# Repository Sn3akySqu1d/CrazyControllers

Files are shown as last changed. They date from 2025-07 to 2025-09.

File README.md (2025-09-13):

# Crazy Controllers

# *Configurable machine learning computer interface glove and joystick*

ARE YOU FINDING GAMES TO HARD?  
DO YOU STRUGGLE WITH ALL THOSE EXTRA KEYS?  
DO YOU WANT TO FEEL SPIRITUALLY CONNECTED TO YOUR SCREEN?  

Well do we have the device for you with crazy controllers.

Crazy controllers presents two unique ways of controlling the game.

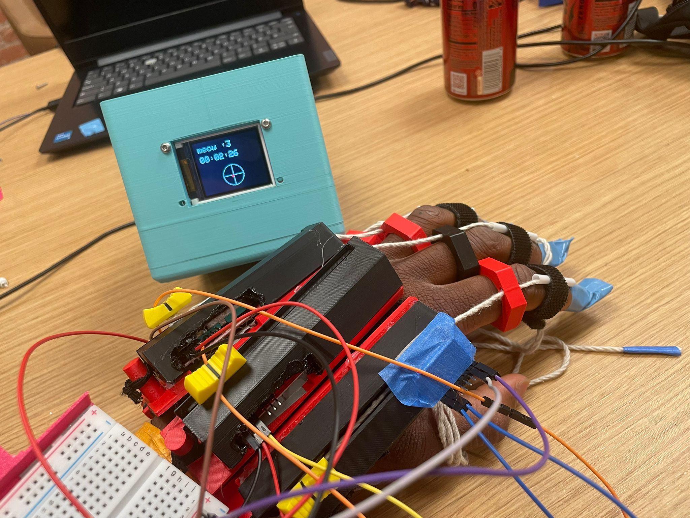
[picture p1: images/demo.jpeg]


## THE GLOVE.

Inspired by the Nintendo Power Glove we created a gauntlet that is able to recognise different gestures based on the position of your hand using an artificial neural network. Allowing you to control your computer and games in fun, unique ways.



We used potentiometer analog sliders and an IMU to read the current state of the hand position, the IMU providing the detail on the orientation of the hand using its accelerometer and using the analogue sliders connected to strings in antagonistic pairs to find out the extension of each finger. These sensor values are then sent along the serial monitor and parsed by a python script running on the computer which uses them to predict the current gesture based on a large csv file contianing sensor values and their corresponding gestures.

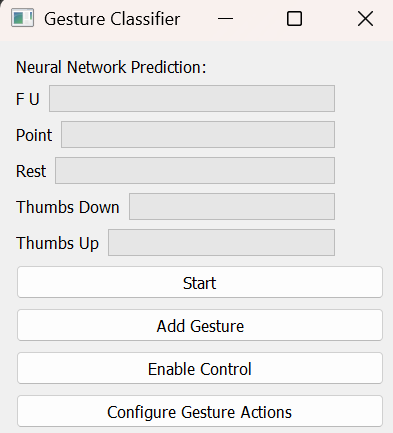
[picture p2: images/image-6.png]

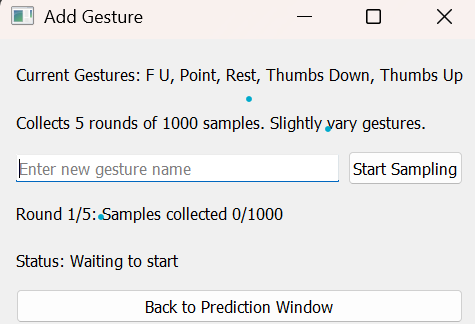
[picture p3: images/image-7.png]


The glove uses an artificial neural network built in tensorflow to classify between the different gestures based on the sensor values, you can also add your own gestures and assign them to computer inputs directly though the python gui.



## THE JOYSTICK.

Complementing the gloves, a more portable companion was developed. We went on a little sidequest to also build this cute cube controller using an ESP32 microcontroller, and connected it to a generic joystick breakout module and a 1.8" 160x128 TFT Display. The joystick is controllable in both X and Y axes and has a switch you can click, similar to thumbsticks you'd find on modern controllers.

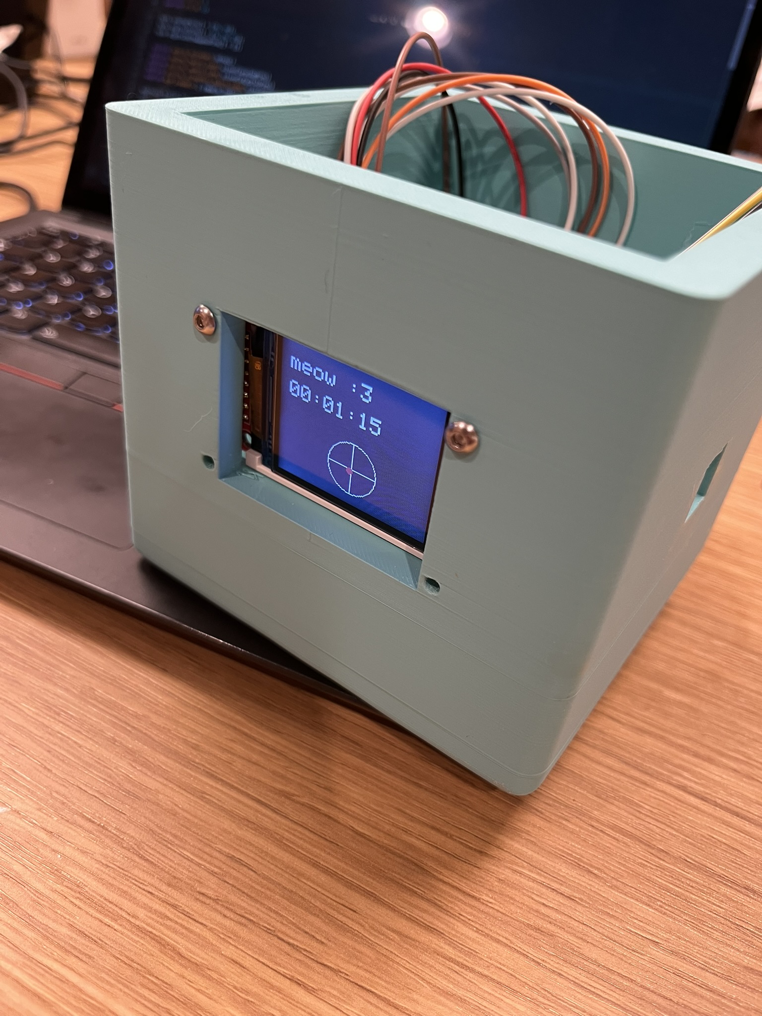
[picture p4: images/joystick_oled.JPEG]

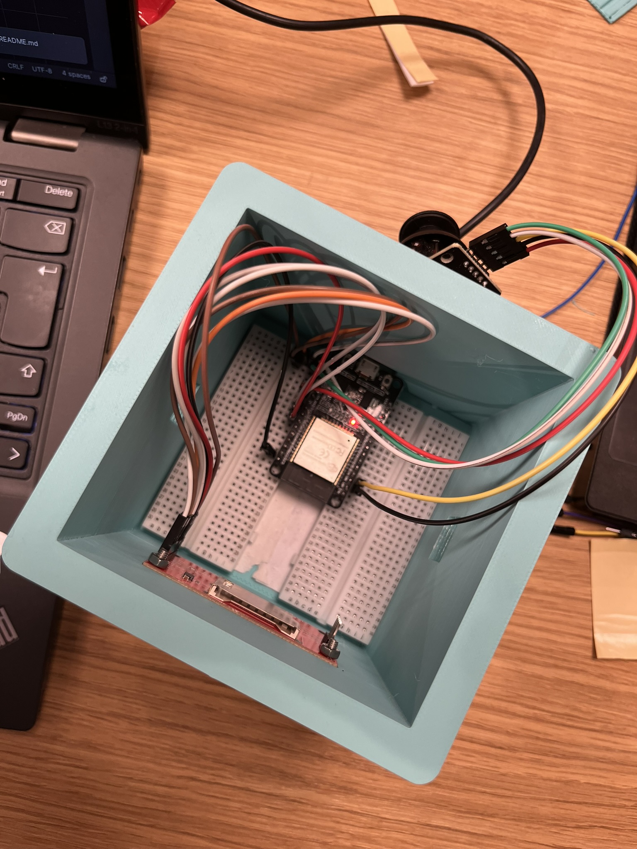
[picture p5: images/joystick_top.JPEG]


Getting this to work was a bit tricky since ESP32s don't do USB HID natively (the protocol for controller input), so we experimented with serial feeding via IBus to send the joystick data over serial and used vJoy and vJoySerialFeeder to turn it into a virtual joystick controller that a laptop recognises.

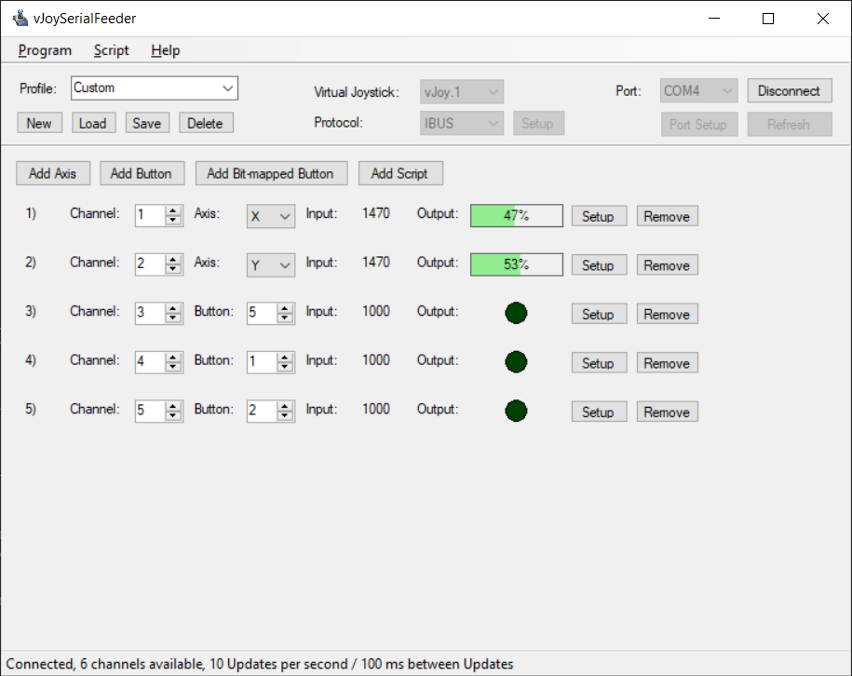
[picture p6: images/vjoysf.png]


Calibrating the joysticks was super annoying, they never centre exactly and constantly drift (it drifts just by looking at it T-T), so we mapped readings to between 1000 and 2000 (~1500 centre, with a deadzone). The screen displays uptime and a cool live joystick visualiser (perfect for crying at the sight of stick drift :sob:).

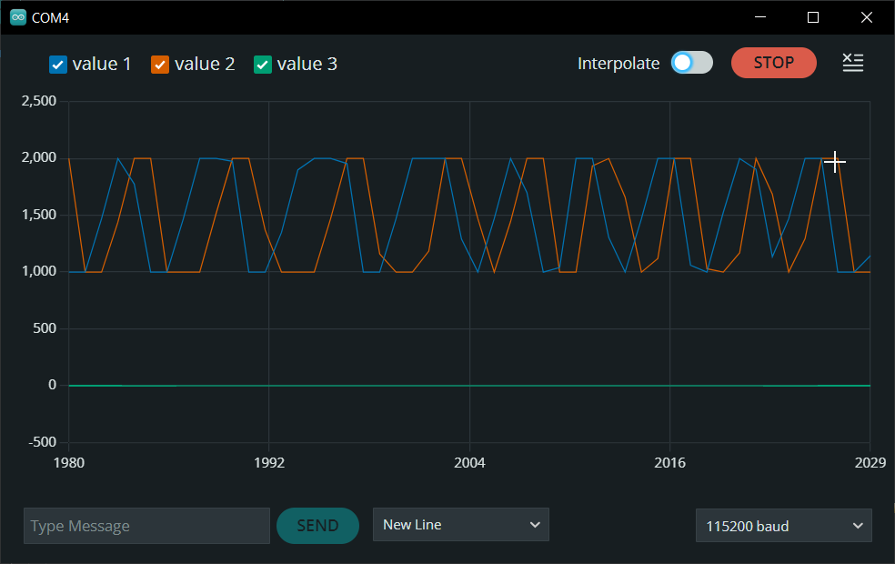
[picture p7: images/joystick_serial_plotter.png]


For an individual demo of the joystick, see [this](https://www.youtube.com/watch?v=Vyi5VYunwlE) video where I tested it out on my game for Juice (Hack Club) :).

# Progress and Pics

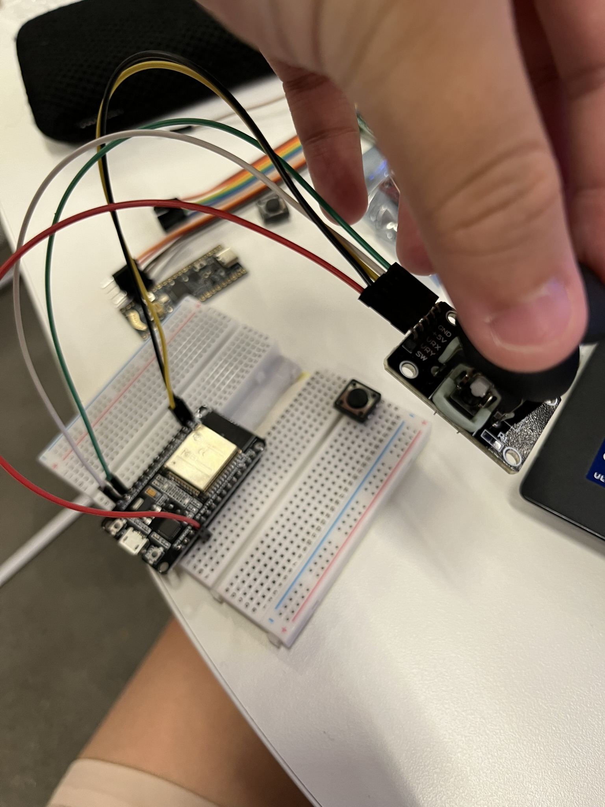
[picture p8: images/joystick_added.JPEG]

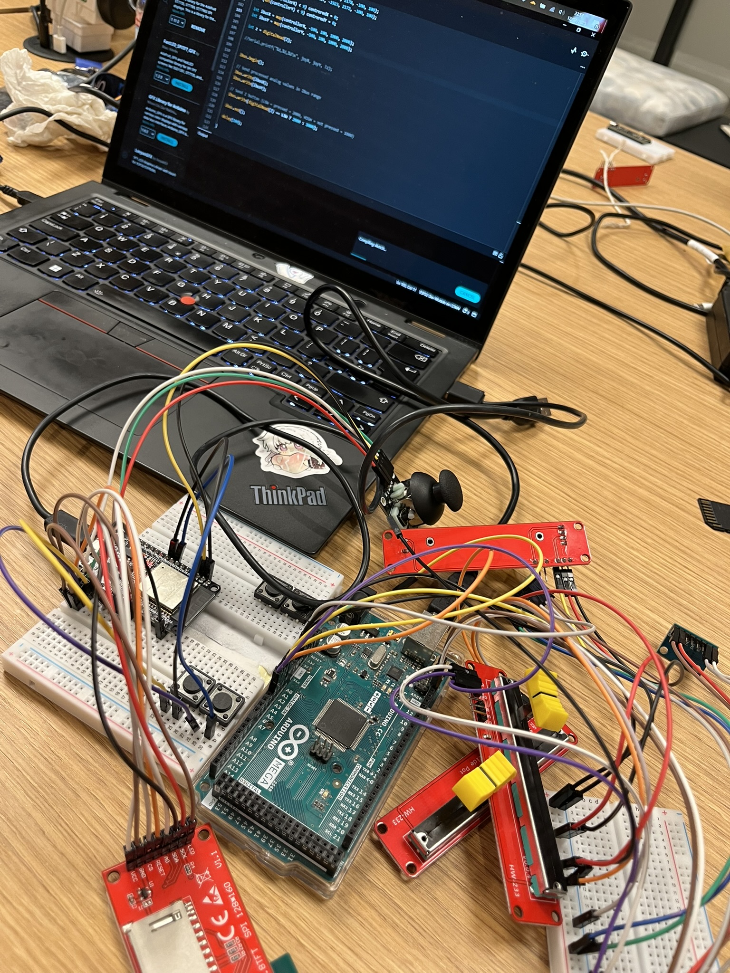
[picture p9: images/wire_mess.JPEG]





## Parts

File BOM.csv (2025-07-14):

Component | source | cost(usd) | link
Velcro | target | 6.19 | https://www.target.com/p/velcro-4-39-x-2-34-industrial-strength-tape/-/A-85028238#lnk=sametab
Arduino mega | home | 49.90 | https://store-usa.arduino.cc/products/arduino-mega-2560-rev3?gad_campaignid=21317508903
ESP32-WROOM DevKit | home | 8.09 | https://www.digikey.com/en/products/detail/espressif-systems/ESP32-DEVKITC-32UE/12091813?gQT=2
analog joystick breakout module | hardware shop | 5.99 | https://www.microcenter.com/product/646122/Joystick_Module?gQT=1
1.8" 160x128 LCD display | hardware shop | 9.99 | https://www.amazon.com/DSD-TECH-Display-Interface-Arduino/dp/B07WDJ3TV6?gQT=2
string/elastic | target | 8.99 | https://www.target.com/p/rope-twine-50-39-pack-up-38-up-8482/-/A-89825708#lnk=sametab
analog slider * 4 | hardware shop | 6.2 | https://www.aliexpress.com/item/1005005517675853.html?utparam-url=scene%3Asearch%7Cquery_from%3A
jumper wires | hardware shop | 0.89 | https://www.aliexpress.us/item/3256806429994553.html?src=google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
straws | scavanged | 0 | N/A
tape | hardware shop | 7.28 | https://www.target.com/p/gorilla-double-sided-tape/-/A-78262323#lnk=sametab
breadboard | hardware shop | 0.55 | https://www.aliexpress.us/item/3256808365241330.html?src=google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
prints | hardware shop | 0 | N/A

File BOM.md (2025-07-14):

| Component | Source | Cost (USD) | Link |
|---|---|---|---|
| Velcro | Target | 6.19 | [Velcro - Industrial Strength Tape](https://www.target.com/p/velcro-4-39-x-2-34-industrial-strength-tape/-/A-85028238#lnk=sametab) |
| Arduino Mega | Home | 49.90 | [Arduino Mega 2560 Rev3](https://store-usa.arduino.cc/products/arduino-mega-2560-rev3?gad_campaignid=21317508903) |
| ESP32-WROOM DevKit | Home | 8.09 | [ESP32-WROOM DevKit](https://www.digikey.com/en/products/detail/espressif-systems/ESP32-DEVKITC-32UE/12091813?gQT=2) |
| Analog Joystick Breakout Module | Hardware Shop | 5.99 | [Generic Joystick Module](https://www.microcenter.com/product/646122/Joystick_Module?gQT=1) |
| 1.8" SPI 128x160 TFT Display MSP1803 | Hardware Shop | 9.99 | [Display](https://www.amazon.com/DSD-TECH-Display-Interface-Arduino/dp/B07WDJ3TV6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) |
| String/Elastic | Target | 8.99 | [Rope/Twine 50' Pack](https://www.target.com/p/rope-twine-50-39-pack-up-38-up-8482/-/A-89825708#lnk=sametab) |
| Analog Slider ×4 | Hardware Shop | 6.20 | [Analog Slide Potentiometer (x4)](https://www.aliexpress.com/item/1005005517675853.html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) |
| Jumper Wires | Hardware Shop | 0.89 | [Jumper Wires](https://www.aliexpress.us/item/3256806429994553.html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) |
| Straws | Scavenged | 0.00 | N/A |
| Tape | Hardware Shop | 7.28 | [Gorilla Double-Sided Tape](https://www.target.com/p/gorilla-double-sided-tape/-/A-78262323#lnk=sametab) |
| Breadboard | Hardware Shop | 0.55 | [Mini Breadboard](https://www.aliexpress.us/item/3256808365241330.html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) |
| Prints | Hardware Shop | 0.00 | N/A |

**Subtotal**: US$104.07

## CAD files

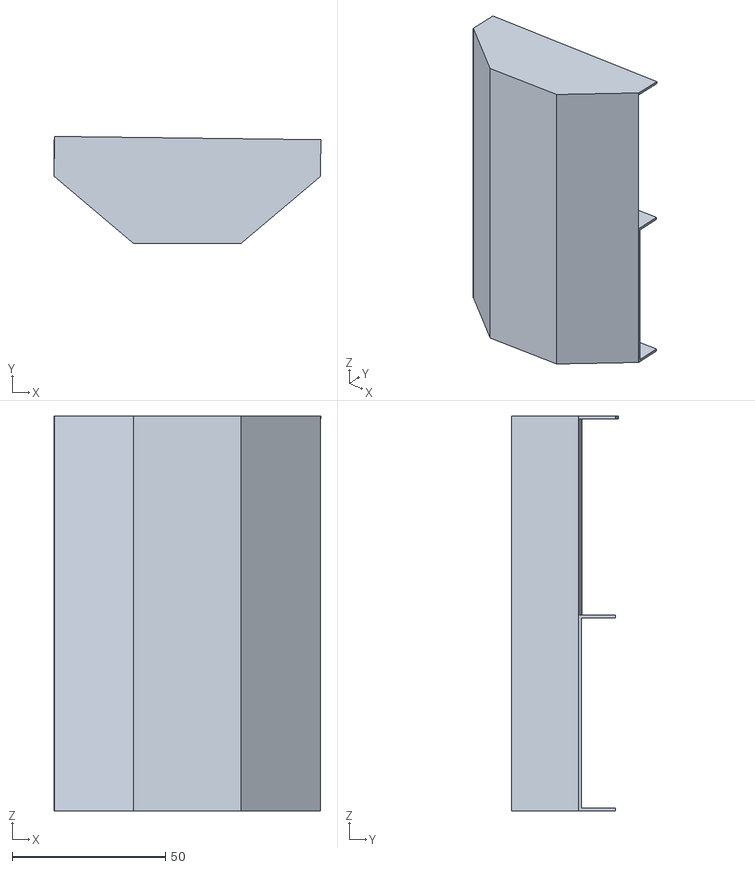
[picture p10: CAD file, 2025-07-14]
CAD/mainModuleNew.stl
87.1 x 35.0 x 129.0

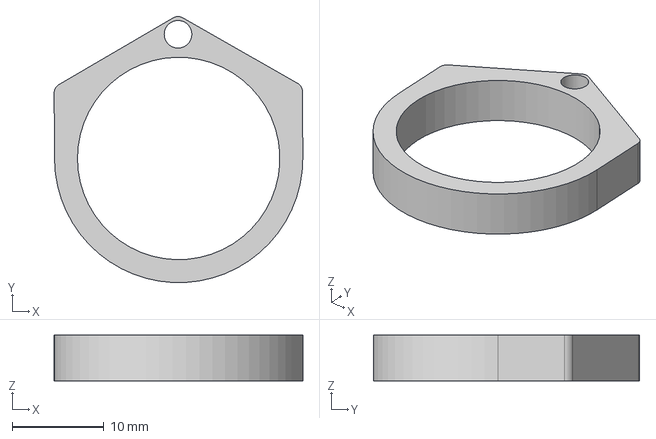
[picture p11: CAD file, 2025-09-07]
CAD/ring new.step
27.0 x 28.9 x 5.00 mm

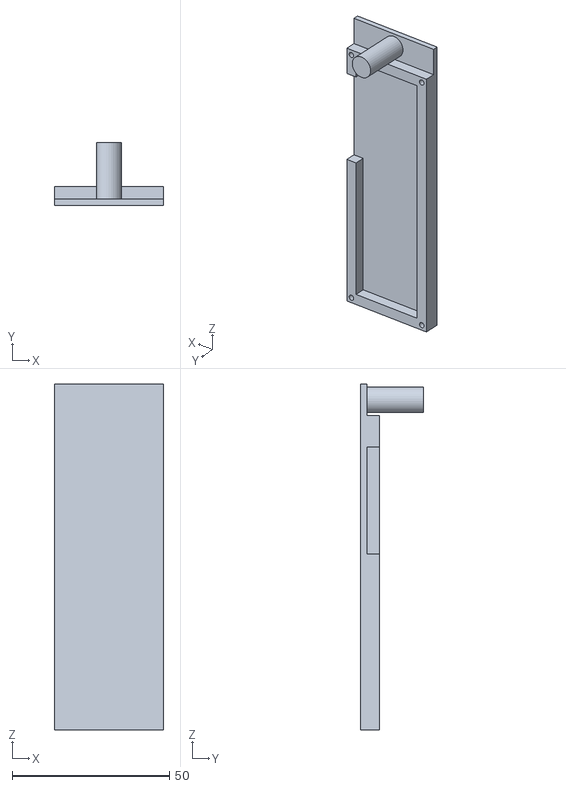
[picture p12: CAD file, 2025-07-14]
CAD/ANALOG SWITCH BOTTOM v1.stl
34.6 x 20.0 x 110.0

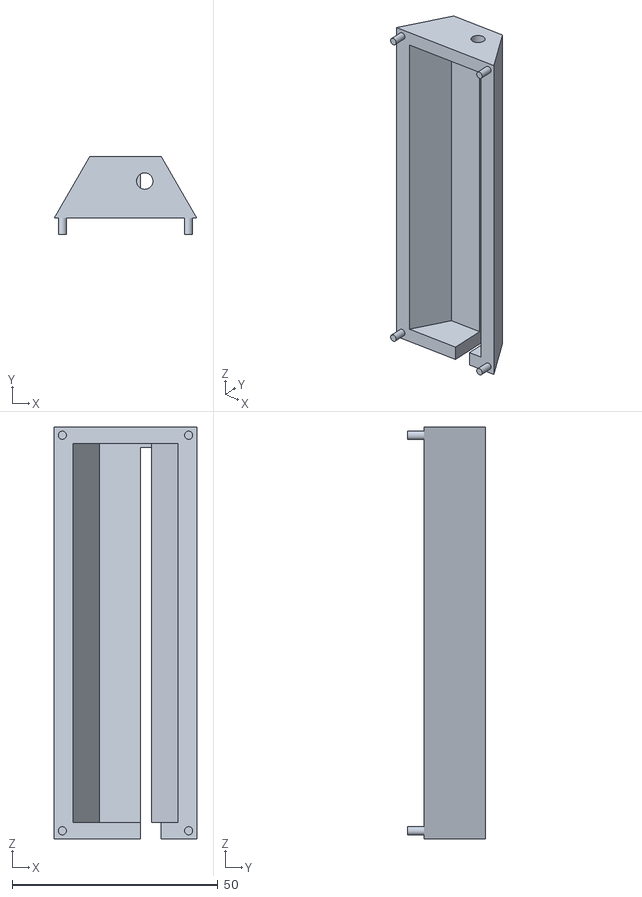
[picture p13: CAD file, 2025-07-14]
CAD/Body1.stl
34.6 x 19.0 x 100.0

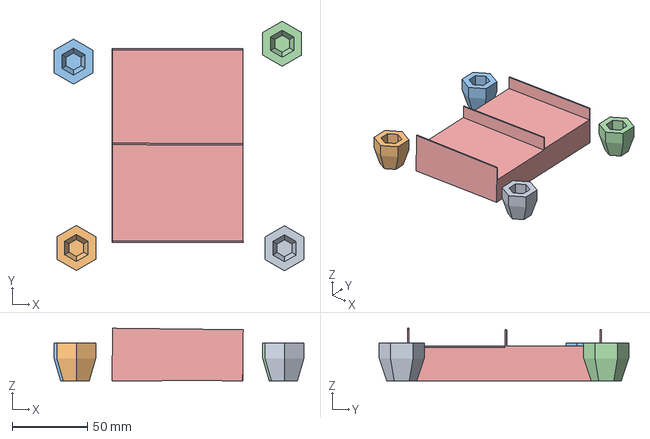
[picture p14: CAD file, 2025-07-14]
CAD/final.3mf
166.4 x 166.1 x 35.0 mm
fingertip new.stl x 4
mod.stl

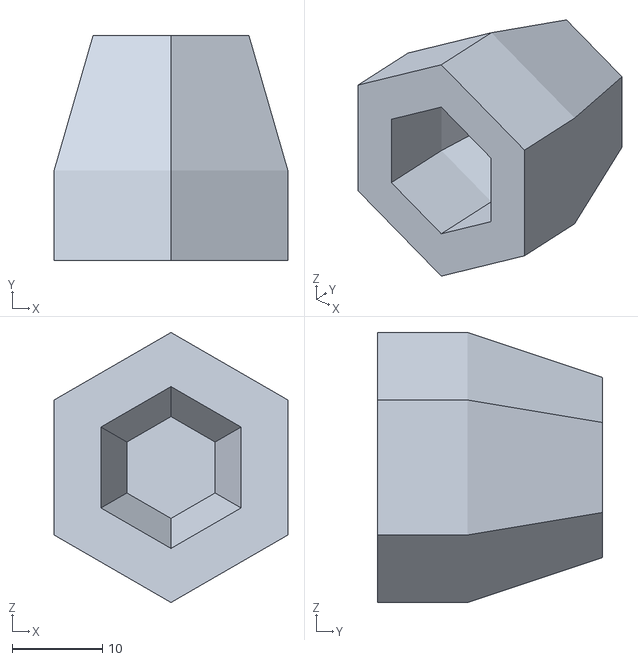
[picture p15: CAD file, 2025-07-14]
CAD/fingertip new.stl
26.0 x 25.0 x 30.0

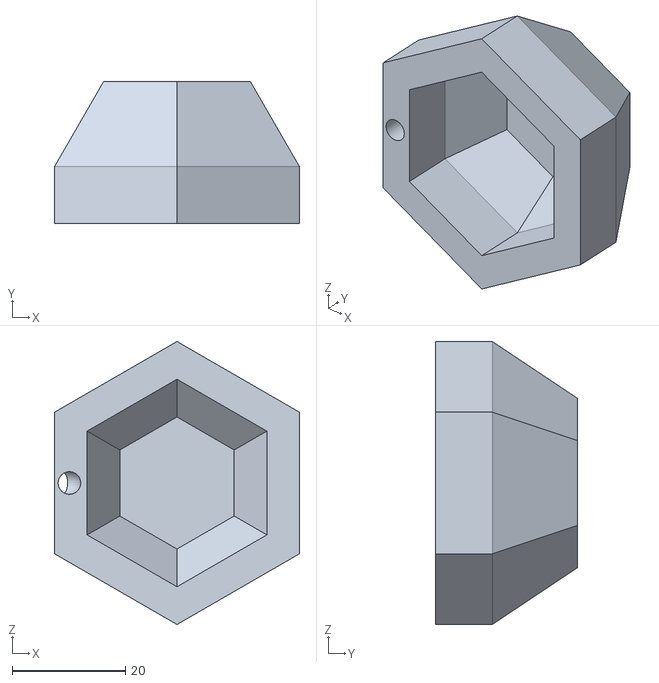
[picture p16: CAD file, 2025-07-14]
CAD/Body2.stl
43.3 x 25.0 x 50.0

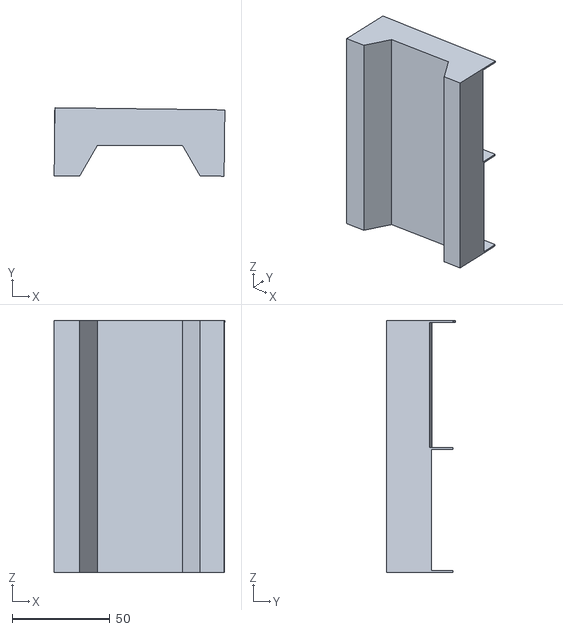
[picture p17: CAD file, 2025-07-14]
CAD/mods.stl
87.4 x 35.1 x 129.0

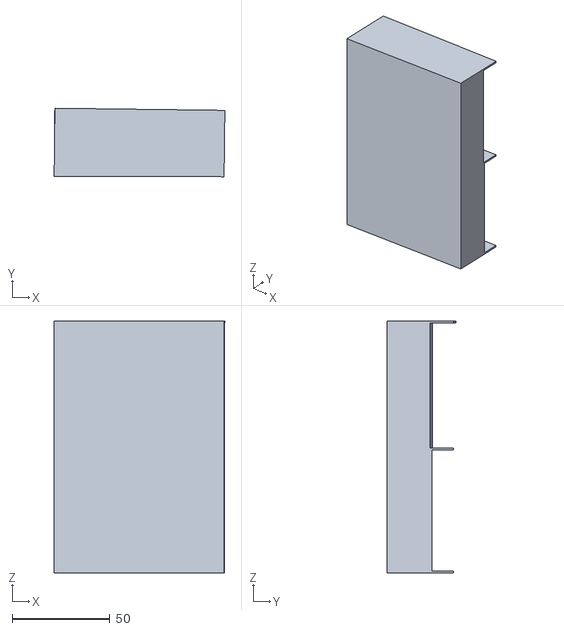
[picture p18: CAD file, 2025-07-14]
CAD/mod.stl
87.4 x 35.1 x 129.0

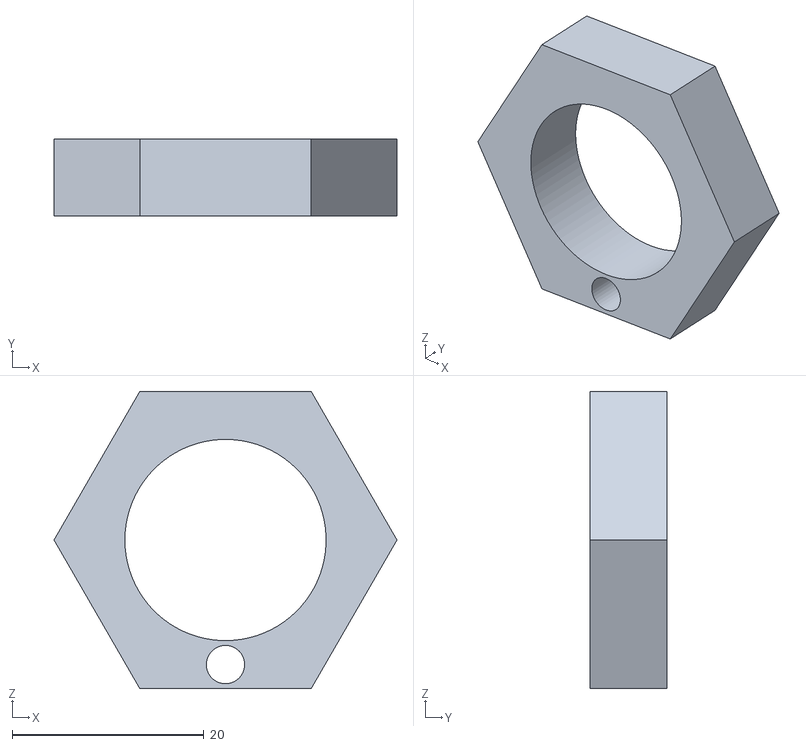
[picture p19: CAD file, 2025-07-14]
CAD/RING bigger.stl
35.8 x 8.00 x 31.0

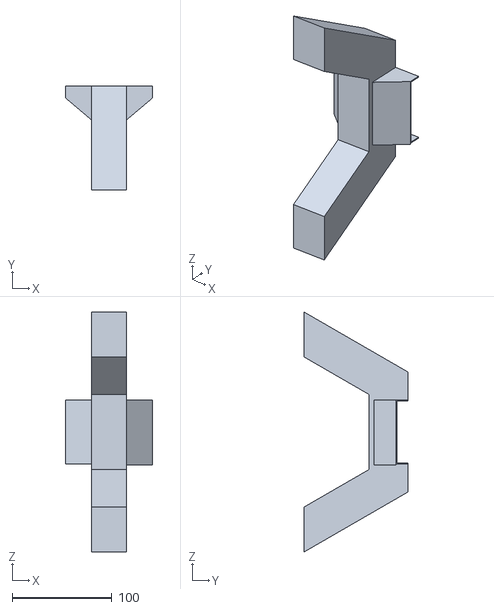
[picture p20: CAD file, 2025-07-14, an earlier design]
CAD/ARCHIVE/mainModule.stl
87.0 x 103.9 x 240.0

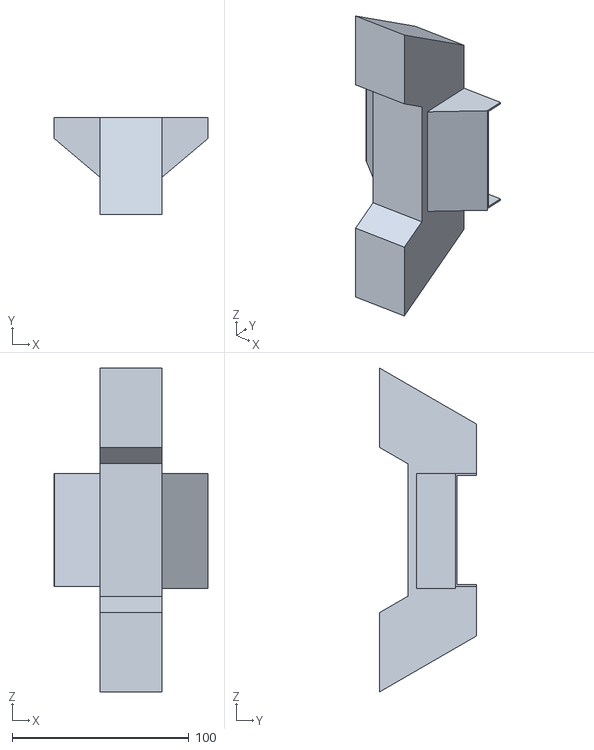
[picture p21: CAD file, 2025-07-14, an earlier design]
CAD/ARCHIVE/main module v2.stl
87.0 x 55.0 x 183.5

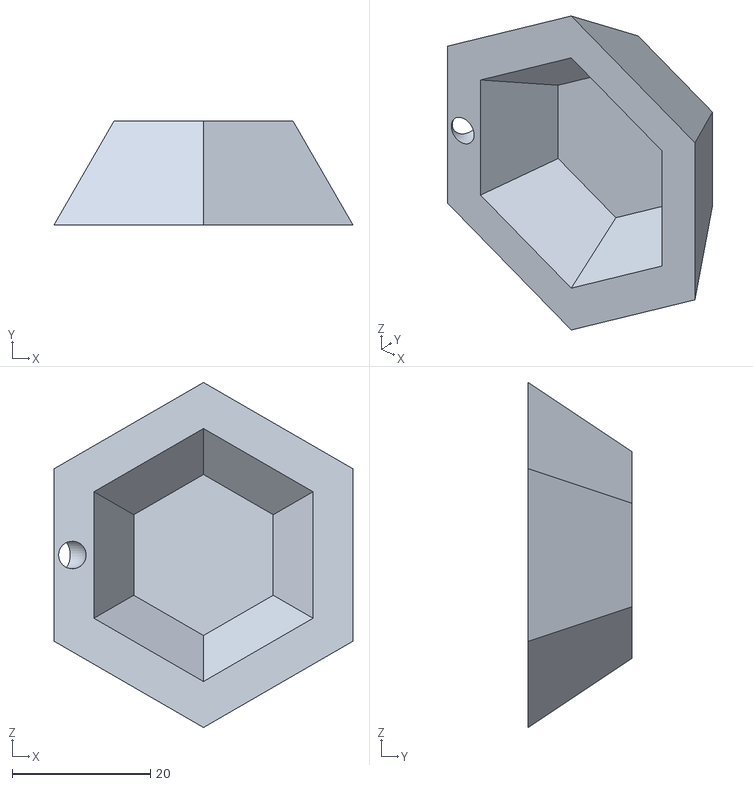
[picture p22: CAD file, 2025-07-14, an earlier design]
CAD/ARCHIVE/fingertip.stl
43.3 x 15.0 x 50.0

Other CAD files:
CAD/newer ring.step

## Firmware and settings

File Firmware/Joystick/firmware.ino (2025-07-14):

#include <Adafruit_GFX.h>
#include <Adafruit_ST7735.h>
#include <SPI.h>
#include "ibus.h"

#define INTERNAL_LED 2

#define X 39
#define Y 36
#define Z 4

#define TFT_CS 5
#define TFT_DC 17

byte analogPins[] = {39, 36};
byte digitalPins[] = {4};
byte digitalBitmappedPins[] = {};

#define ANALOG_REFERENCE DEFAULT
#define ANALOG_INPUTS_COUNT sizeof(analogPins)
#define DIGITAL_INPUTS_COUNT sizeof(digitalPins)
#define DIGITAL_BITMAPPED_INPUTS_COUNT sizeof(digitalBitmappedPins)
#define NUM_CHANNELS ( (ANALOG_INPUTS_COUNT) + (DIGITAL_INPUTS_COUNT) + (15 + (DIGITAL_BITMAPPED_INPUTS_COUNT))/16 )

Adafruit_ST7735 tft = Adafruit_ST7735(TFT_CS, TFT_DC, -1);
IBus ibus(NUM_CHANNELS);

unsigned long lastDisplayUpdate = 0;
unsigned long prevHours = 999, prevMinutes = 999, prevSeconds = 999;

int lastState = LOW;
int currentState;

int lastDotX = 80, lastDotY = 100;
int gridCentreX = 80, gridCentreY = 92;
int gridSize = 25;

void setup() {
  pinMode(INTERNAL_LED, OUTPUT);
  pinMode(Z, INPUT_PULLUP);
  Serial.begin(115200);

  tft.initR(INITR_BLACKTAB);  
  tft.fillScreen(ST77XX_BLACK);
  tft.setRotation(3);
  tft.setTextColor(ST77XX_WHITE);
  tft.setTextSize(2);
  tft.setCursor(10, 10);
  tft.println("meow :3");
  drawJoystickGrid();
}

void drawJoystickGrid() {
  tft.drawLine(gridCentreX - gridSize, gridCentreY, gridCentreX + gridSize, gridCentreY, ST77XX_WHITE);
  tft.drawLine(gridCentreX, gridCentreY - gridSize, gridCentreX, gridCentreY + gridSize, ST77XX_WHITE);
  tft.drawCircle(gridCentreX, gridCentreY, gridSize, ST77XX_WHITE);
}

void loop() {
  unsigned long currentTime = millis();

  if (currentTime - lastDisplayUpdate >= 1000) {
    unsigned long seconds = currentTime / 1000;
    unsigned long minutes = seconds / 60;
    unsigned long hours = minutes / 60;
    
    seconds = seconds % 60;
    minutes = minutes % 60;
    
    if (hours != prevHours || minutes != prevMinutes || seconds != prevSeconds) {
      tft.fillRect(10, 30, 118, 20, ST77XX_BLACK);
      
      tft.setTextSize(2);
      tft.setCursor(10, 35);
      tft.printf("%02lu:%02lu:%02lu", hours, minutes, seconds);
      
      prevHours = hours;
      prevMinutes = minutes;
      prevSeconds = seconds;
    }
    lastDisplayUpdate = currentTime;
  }
  
  int rawX = analogRead(X);
  int rawY = analogRead(Y);

  int centreredX = rawX - 1917;
  int centreredY = rawY - 1923;

  int controllerX = map(centreredX, -1917, 2178, -100, 100);
  int controllerY = map(centreredY, -1923, 2172, -100, 100);

  if (abs(controllerX) < 9) centreredX = 0;
  if (abs(controllerY) < 9) centreredY = 0;

  int ibusX = map(controllerX, -100, 100, 1000, 2000);
  int ibusY = map(controllerY, -100, 100, 1000, 2000);

  int dotX = gridCentreX + map(controllerY, -100, 100, -gridSize, gridSize);
  int dotY = gridCentreY - map(controllerX, -100, 100, -gridSize, gridSize);

  if (dotX != lastDotX || dotY != lastDotY) {
    tft.fillCircle(lastDotX, lastDotY, 3, ST77XX_BLACK);
    
    if (abs(lastDotY - gridCentreY) <= 3) {
      tft.drawLine(gridCentreX - gridSize, gridCentreY, gridCentreX + gridSize, gridCentreY, ST77XX_WHITE);
    }
    if (abs(lastDotX - gridCentreX) <= 3) {
      tft.drawLine(gridCentreX, gridCentreY - gridSize, gridCentreX, gridCentreY + gridSize, ST77XX_WHITE);
    }
    
    int distanceFromCentre= sqrt((lastDotX - gridCentreX) * (lastDotX - gridCentreX) + 
                                (lastDotY - gridCentreY) * (lastDotY - gridCentreY));
    if (distanceFromCentre >= gridSize - 4) {
      tft.drawCircle(gridCentreX, gridCentreY, gridSize, ST77XX_WHITE);
    }
    
    tft.fillCircle(dotX, dotY, 3, ST77XX_RED);
    
    lastDotX = dotX;
    lastDotY = dotY;
  }

  int z = digitalRead(Z);

  //Serial.printf("%d,%d,%d\n", ibusX, ibusY, !z);
  
  ibus.begin();
  
  ibus.write(ibusY);
  ibus.write(ibusX);
  ibus.write(z == LOW ? 2000 : 1000);

  ibus.end();

  delay(100);

}

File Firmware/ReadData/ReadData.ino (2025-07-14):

#include <Wire.h>
#include <Adafruit_Sensor.h>
#include <Adafruit_ADXL345_U.h>

Adafruit_ADXL345_Unified accel1 = Adafruit_ADXL345_Unified(0x53);

void setup(void) {
  Serial.begin(9600);

  if (!accel1.begin()) {
    while (1);
  }

}

void loop(void) {
  sensors_event_t event1;

  accel1.getEvent(&event1);

  int slider1 = analogRead(A0);
  int slider2 = analogRead(A1);
  int slider3 = analogRead(A2);
  int slider4 = analogRead(A3);

  Serial.print(event1.acceleration.x); Serial.print(",");
  Serial.print(event1.acceleration.y); Serial.print(",");
  Serial.print(event1.acceleration.z); Serial.print(",");

  Serial.print(slider1); Serial.print(",");
  Serial.print(slider2); Serial.print(",");
  Serial.print(slider3); Serial.print(",");
  Serial.println(slider4);

}

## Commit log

2025-07-14 Update EVERYTHING!
    [BOM.csv]
2025-07-14 cad folder restructure
    [fingertip.stl, main module v2.stl, mainModule.stl]
2025-09-07 cad update
    [newer ring.step, ring new.step]
